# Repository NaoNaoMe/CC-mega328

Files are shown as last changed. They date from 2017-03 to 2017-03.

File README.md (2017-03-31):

CC-mega328 Breakout Board
========================================

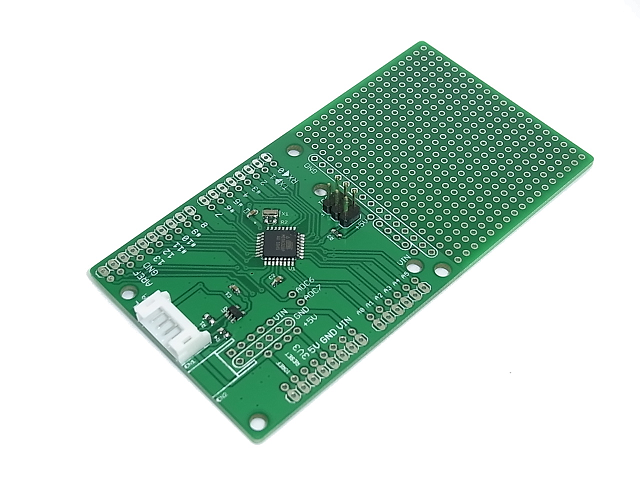
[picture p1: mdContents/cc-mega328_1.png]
CC-mega328 Breakout
  
The CC-mega328 Breakout Board is breakout for the Atmel ATMEGA328P with prototyping area.  
This board shape is dirfferent from Arduino UNO, but it has Arduino Uno V3 style headers.  
There are only the minimal set of parts for running microcontroller. When you make your own circuit boards, this board might be helpful.

### Some highlights of the CC-mega328 Breakout Board:
 1. Main core: [ATMEGA328P](http://www.atmel.com/devices/atmega328p.aspx)
 2. Volatage regulator can be mounted in the extra prototyping area.
 3. Prototyping area 43.94mm(1730mil) x 53.34mm(2100mil)
 4. Measures 99.82mm(3930mil) x 53.34mm(2100mil)

Repository Contents
-------------------
* **/Hardware** - All Eagle design files (.brd, .sch)

Description(Pin Interfaces)
-------------------
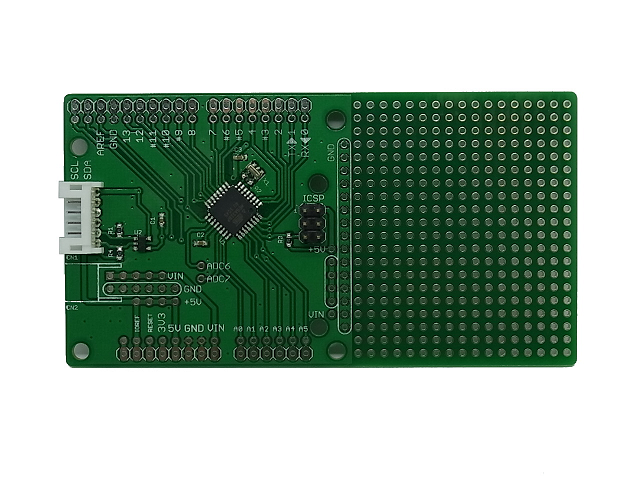
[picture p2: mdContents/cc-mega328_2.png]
TopView


### CN1 Pin Descriptions:
This connector is for Flashing a program microcontroller.  
If you change BOOT MODE, To be selected BOOT MODE before connecting the power supply.  
And also, you can Communicate with ATMEGA328P using "Serial" function.
- **VCC:** Restrictly 5.0VDC or 3.3VDC
- **TX:** PD1 used as UART TX.
- **RX:** PD0 used as UART RX.
- **GND:** GND.
- **RESET:** Reset input to microcontroller.
- **EN:** Connected to 3-stete-buffer gate pin H:Enable RESET input L:Disable RESET input(normally)

If you are interested in more useful uart module, please see the [General Serial Communication Board](https://github.com/NaoNaoMe/General-Serial-Communication-Board).

### CN2 Pin Descriptions:
This connector is as power supply.
You can mount a voltage regulator in the extra prototyping area near the connector.
- **VIN:** Depending on the voltage regulator requirements.
- **GND:** GND.

How to burn bootloader and upload sketch
-------------------
See [this page](BurnBootloader.md)

License
-------------------
The repository is released under [Creative Commons ShareAlike 4.0 International](https://creativecommons.org/licenses/by-sa/4.0/).

Distributed as-is; no warranty is given.

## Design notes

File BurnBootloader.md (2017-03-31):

Burn Bootloader and upload a program for CC-mega328 Breakout Board
========================================

First of all
--------------
You will need the following items for this instruction.
 - Arduino UNO or AVR-ISP and more.
 - FTDI BREAKOUT BOARD(5.0V)
 - reprogramming cable(you should assebele it.)

Software Setup
--------------
No requirements

Hardware Setup
--------------
Refer to the figure below to make reprogramming cable.  
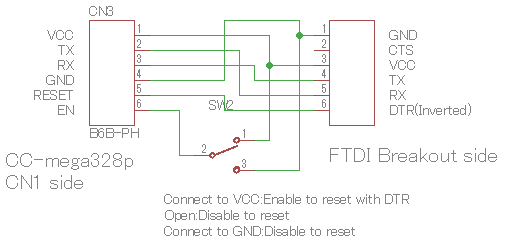
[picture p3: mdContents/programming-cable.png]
CC-mega328 cable


### Connection
The ICSP connector is available on this board.
For example, the following figure is connection with Arduino UNO ISP.  
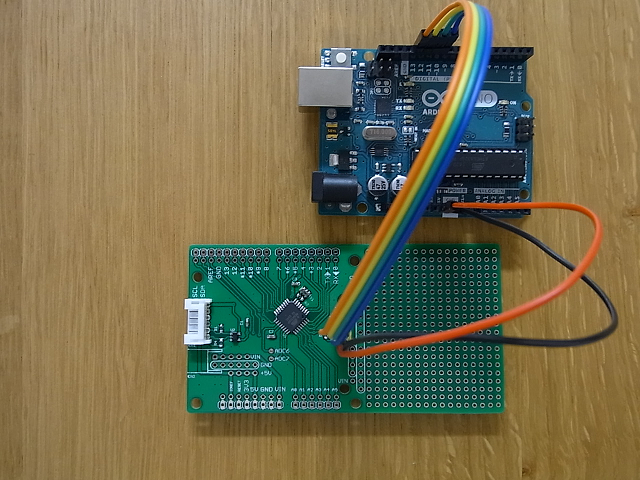
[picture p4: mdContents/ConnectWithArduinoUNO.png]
CC-mega328 with ArduinoUNO as ISP


Burn Bootloader and Upload a program
--------------
Burning the Bootloader is same way as original Arduino UNO.  

### Upload a program
Before you upload your program, please check whether the switch(reprogramming cable) position is tied low(GND).  
The bootloader check port condtion when turn on itself.  
Click the Upload button in the IDE. Wait a few seconds. If successful, the message "Done uploading." will appear in the status bar.

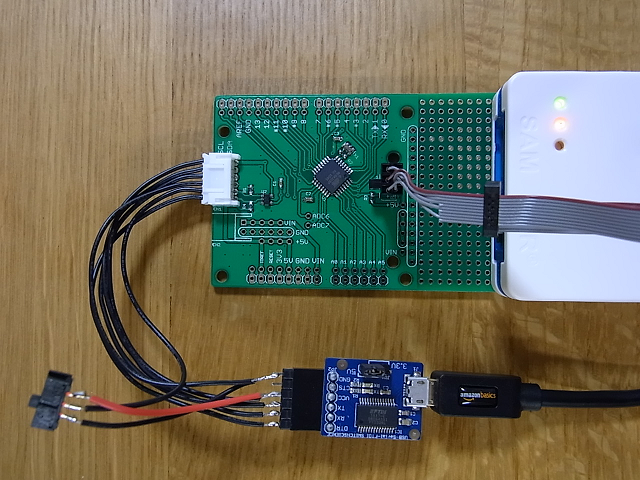
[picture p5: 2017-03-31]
mdContents/ConnectWithATMEL-ICE.png

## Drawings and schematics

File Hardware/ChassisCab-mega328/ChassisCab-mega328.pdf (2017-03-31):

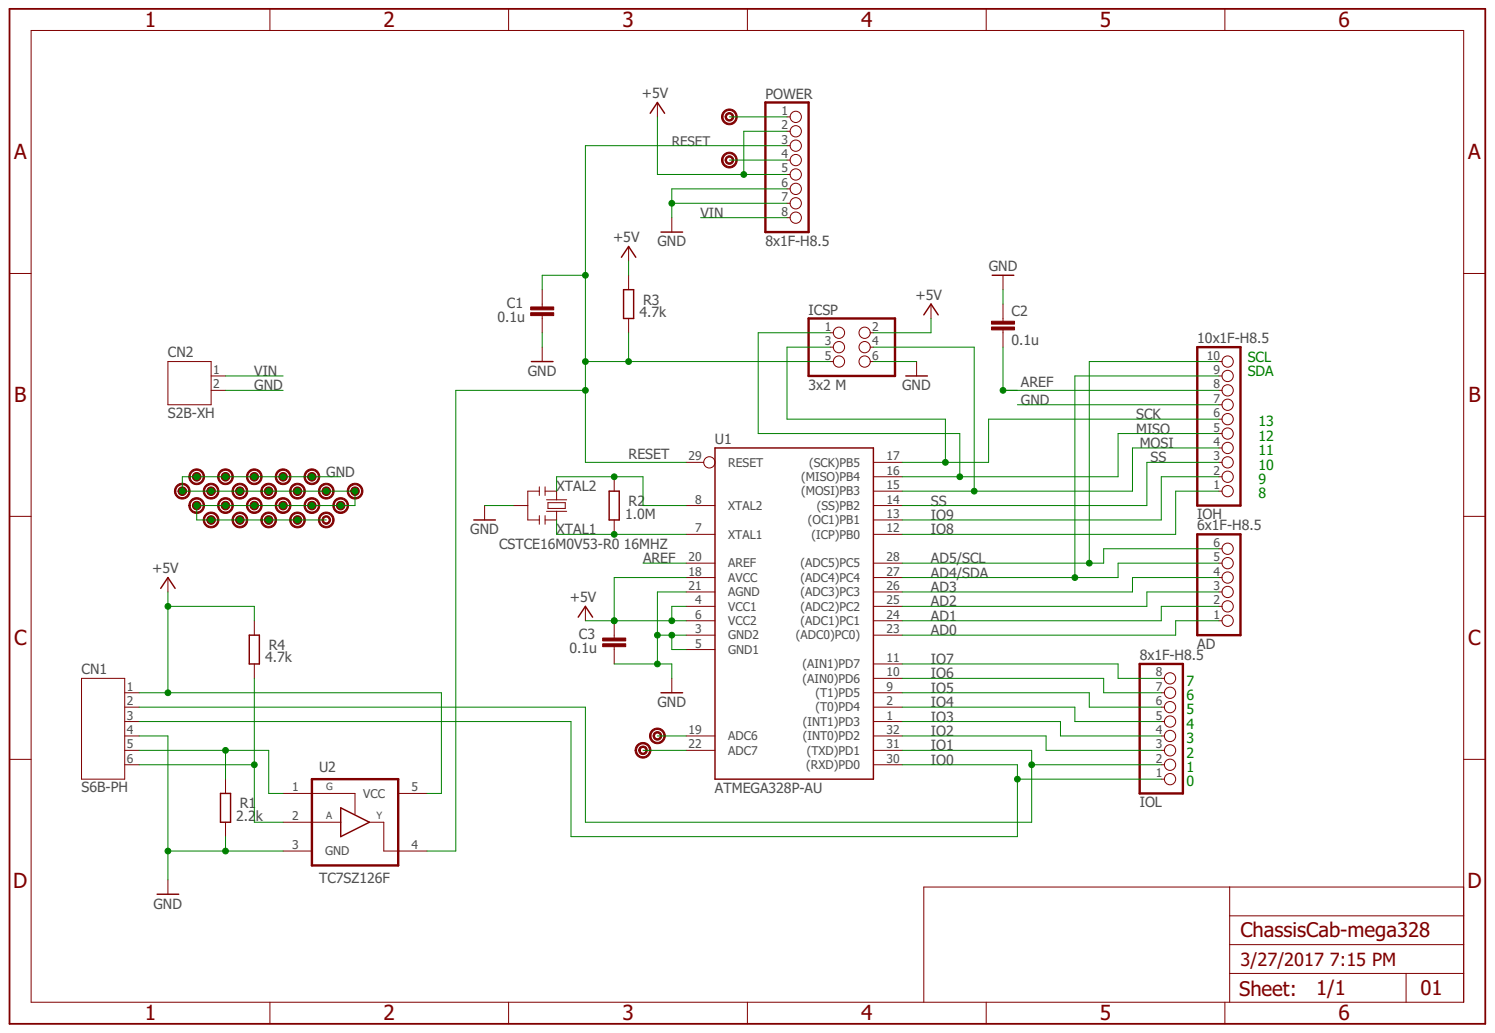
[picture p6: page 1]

16
15
14 SS

3 | AD0
5 | 8x1F-H8.5 11 IO7

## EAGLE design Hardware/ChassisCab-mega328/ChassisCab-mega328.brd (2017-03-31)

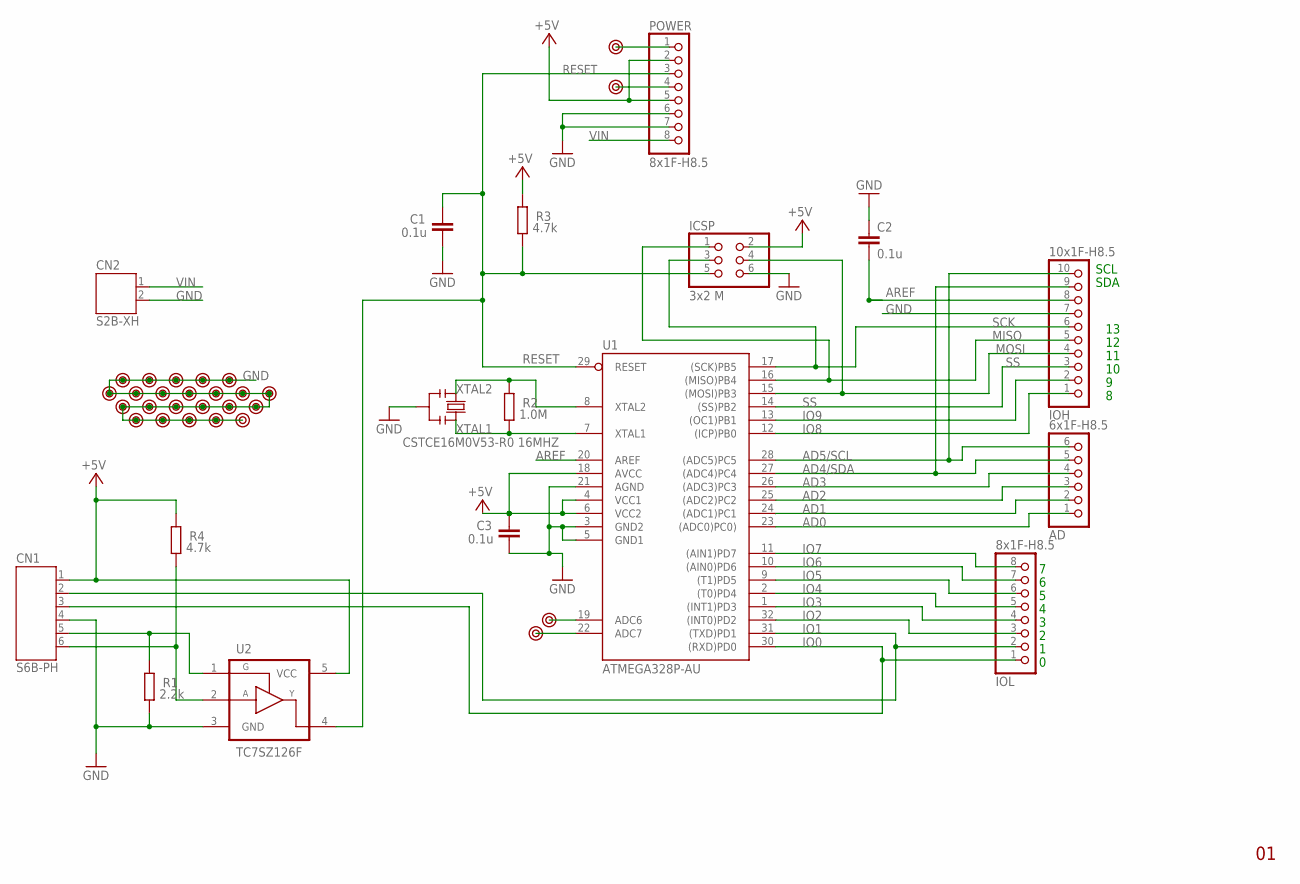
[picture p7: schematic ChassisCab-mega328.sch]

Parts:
AD: 6x1F-H8.5; 1X06
C1, C2, C3: 0.1u; C0603
CN1: S6B-PH
CN2: S2B-XH
ICSP: 3x2 M; 2X03
IOH: 10x1F-H8.5; 1X10
IOL: 8x1F-H8.5; 1X08
POWER: 8x1F-H8.5; 1X08
R1: 2.2k; R0603
R2: 1.0M; R0603
R3, R4: 4.7k; R0603
U1: ATMEGA328P-AU; TQFP32
U2: TC7SZ126F; SMV
U$1, U$2, U$3, U$4, U$5, U$6, U$7, U$8, U$9, U$10, U$11, U$12, U$13, U$14, U$15, U$16, U$17, U$18, U$19, U$20, U$21, U$22, U$23, U$24, U$25, U$26, U$27: PAD
X1: CSTCE16M0V53-R0 16MHZ; CSTCE_V

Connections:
+5V: C3.2, CN1.1, ICSP.2, POWER.2, POWER.5, R3.2, R4.2, U1.4 (VCC1), U1.6 (VCC2), U1.18 (AVCC), U2.5 (VCC)
AD0: AD.1, U1.23 ((ADC0)PC0))
AD1: AD.2, U1.24 ((ADC1)PC1)
AD2: AD.3, U1.25 ((ADC2)PC2)
AD3: AD.4, U1.26 ((ADC3)PC3)
AD4/SDA: AD.5, IOH.9, U1.27 ((ADC4)PC4)
AD5/SCL: AD.6, IOH.10, U1.28 ((ADC5)PC5)
AD6: U1.19 (ADC6), U$1.1
AD7: U1.22 (ADC7), U$2.1
AREF: C2.2, IOH.8, U1.20 (AREF)
GND: C1.1, C2.1, C3.1, CN1.4, CN2.2, ICSP.6, IOH.7, POWER.6, POWER.7, R1.1, U1.3 (GND2), U1.5 (GND1), U1.21 (AGND), U2.3 (GND), U$3.1, U$4.1, U$5.1, U$6.1, U$7.1, U$8.1, U$9.1, U$10.1, U$11.1, U$12.1, U$13.1, U$14.1, U$15.1, U$16.1, U$17.1, U$18.1, U$19.1, U$20.1, U$21.1, U$22.1, U$23.1, U$24.1, U$27.1, X1.2
IO0: CN1.3, IOL.1, U1.30 ((RXD)PD0)
IO1: CN1.2, IOL.2, U1.31 ((TXD)PD1)
IO2: IOL.3, U1.32 ((INT0)PD2)
IO3: IOL.4, U1.1 ((INT1)PD3)
IO4: IOL.5, U1.2 ((T0)PD4)
IO5: IOL.6, U1.9 ((T1)PD5)
IO6: IOL.7, U1.10 ((AIN0)PD6)
IO7: IOL.8, U1.11 ((AIN1)PD7)
IO8: IOH.1, U1.12 ((ICP)PB0)
IO9: IOH.2, U1.13 ((OC1)PB1)
MISO: ICSP.1, IOH.5, U1.16 ((MISO)PB4)
MOSI: ICSP.4, IOH.4, U1.15 ((MOSI)PB3)
unnamed: CN1.5, R1.2, U2.1 (G)
unnamed: CN1.6, R4.1, U2.2 (A)
unnamed: POWER.1, U$25.1
unnamed: POWER.4, U$26.1
RESET: C1.2, ICSP.5, POWER.3, R3.1, U1.29 (RESET), U2.4 (Y)
SCK: ICSP.3, IOH.6, U1.17 ((SCK)PB5)
SS: IOH.3, U1.14 ((SS)PB2)
VIN: CN2.1, POWER.8
XTAL1: R2.1, U1.7 (XTAL1), X1.3
XTAL2: R2.2, U1.8 (XTAL2), X1.1

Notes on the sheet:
SDA
SCL

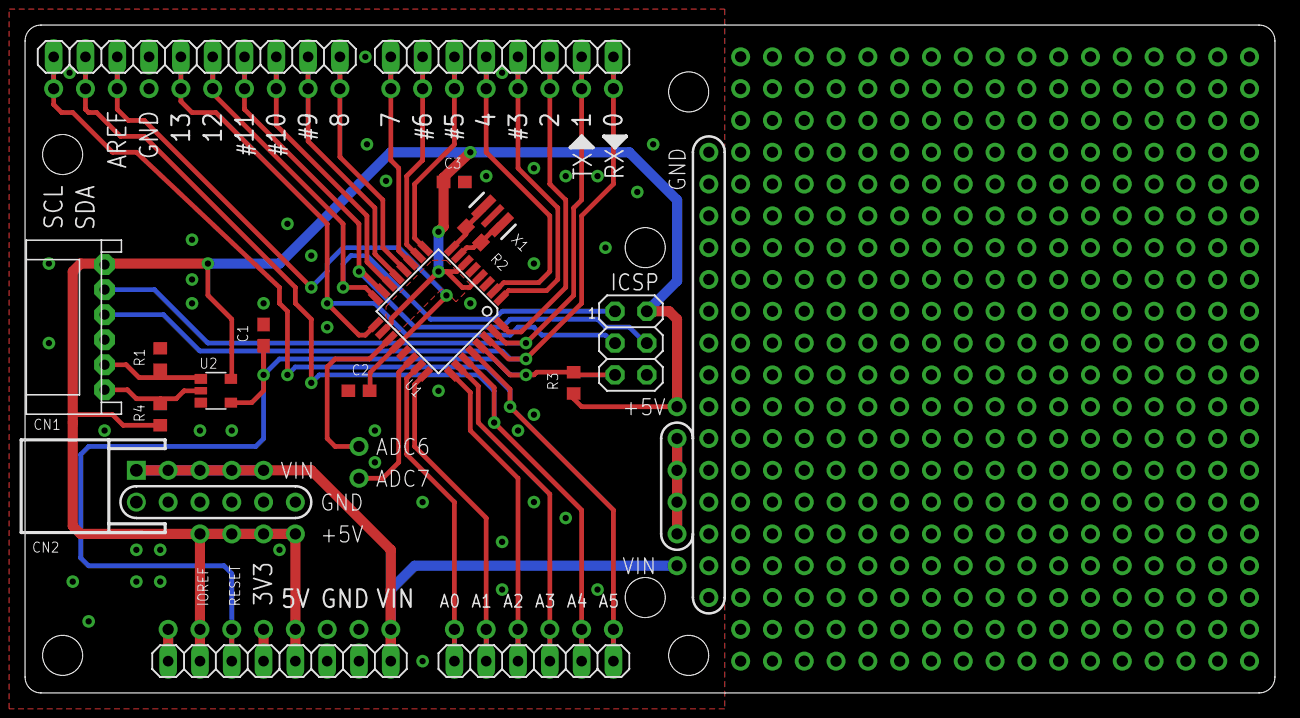
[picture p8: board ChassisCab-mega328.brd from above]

Board: 2 copper layers, 99.8 x 53.3 mm, 44 parts (0 on the bottom side), 33 nets.

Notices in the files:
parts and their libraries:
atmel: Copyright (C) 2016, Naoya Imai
